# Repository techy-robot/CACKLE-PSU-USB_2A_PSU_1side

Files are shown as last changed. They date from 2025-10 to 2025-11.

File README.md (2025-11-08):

---
modified: 2025-11-07T22:09:18-07:00
---

# USB Only PSU one side

> [!TIP]
> This board is part of a larger modular control board ecosystem, [CACKLE](https://github.com/techy-robot/CACKLE)

The main ICs are an mcu, and a 5v 2a switching regulator. The system can theoretically handle 20 volt spikes, but this is mostly meant for 5v output on one side only.

The MCU has several purposes:
- Manage USB-C PD negotiations over the CC pins (built in PHY)
- Report voltage & current sensor data over the bus
- Act as a host adapter to convert USB or SPI data to rs485 bus commands and back. Helpful for debugging the system via a laptop, or if your main compute board needs to control the motors and sensors and doesn't have RS485 built in.

The CH32X035G8U6 MCU will be used, though I may swap to a STM32G071 x8/xB for sourcing reasons, which also implements usb pd (no usb comm) but is a little more expensive. To get a  QFN28/32 chip with USB PD, I need the N version. My options on digikey are STM32G071GBU6N ($2.74) and STM32G071KBU6N ($2.94)

Also looking for USB C connectors on [DigiKey](https://www.digikey.com/en/products/filter/usb-dvi-hdmi-connector-assemblies/312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).

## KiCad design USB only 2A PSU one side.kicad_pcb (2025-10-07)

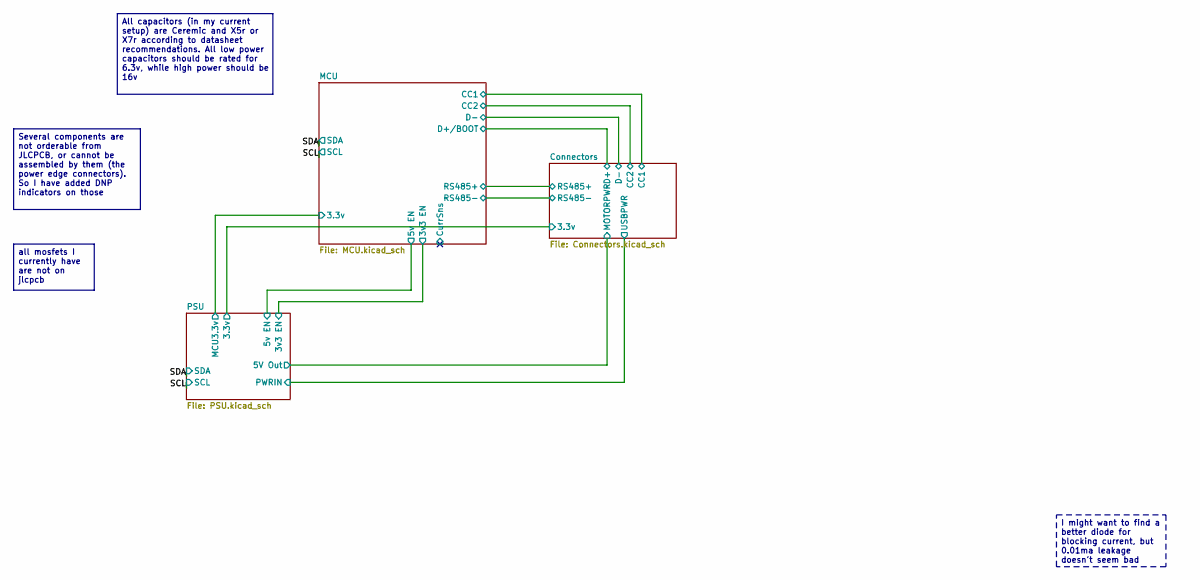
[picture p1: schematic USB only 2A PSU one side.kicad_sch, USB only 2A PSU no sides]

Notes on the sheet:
All capacitors (in my current setup) are Ceremic and X5r or X7r according to datasheet recommendations. All low power capacitors should be rated for 6.3v, while high power should be 16v
Several components are not orderable from JLCPCB, or cannot be assembled by them (the power edge connectors). So I have added DNP indicators on those
all mosfets I currently have are not on jlcpcb
I might want to find a better diode for blocking current, but 0.01ma leakage doesn't seem bad

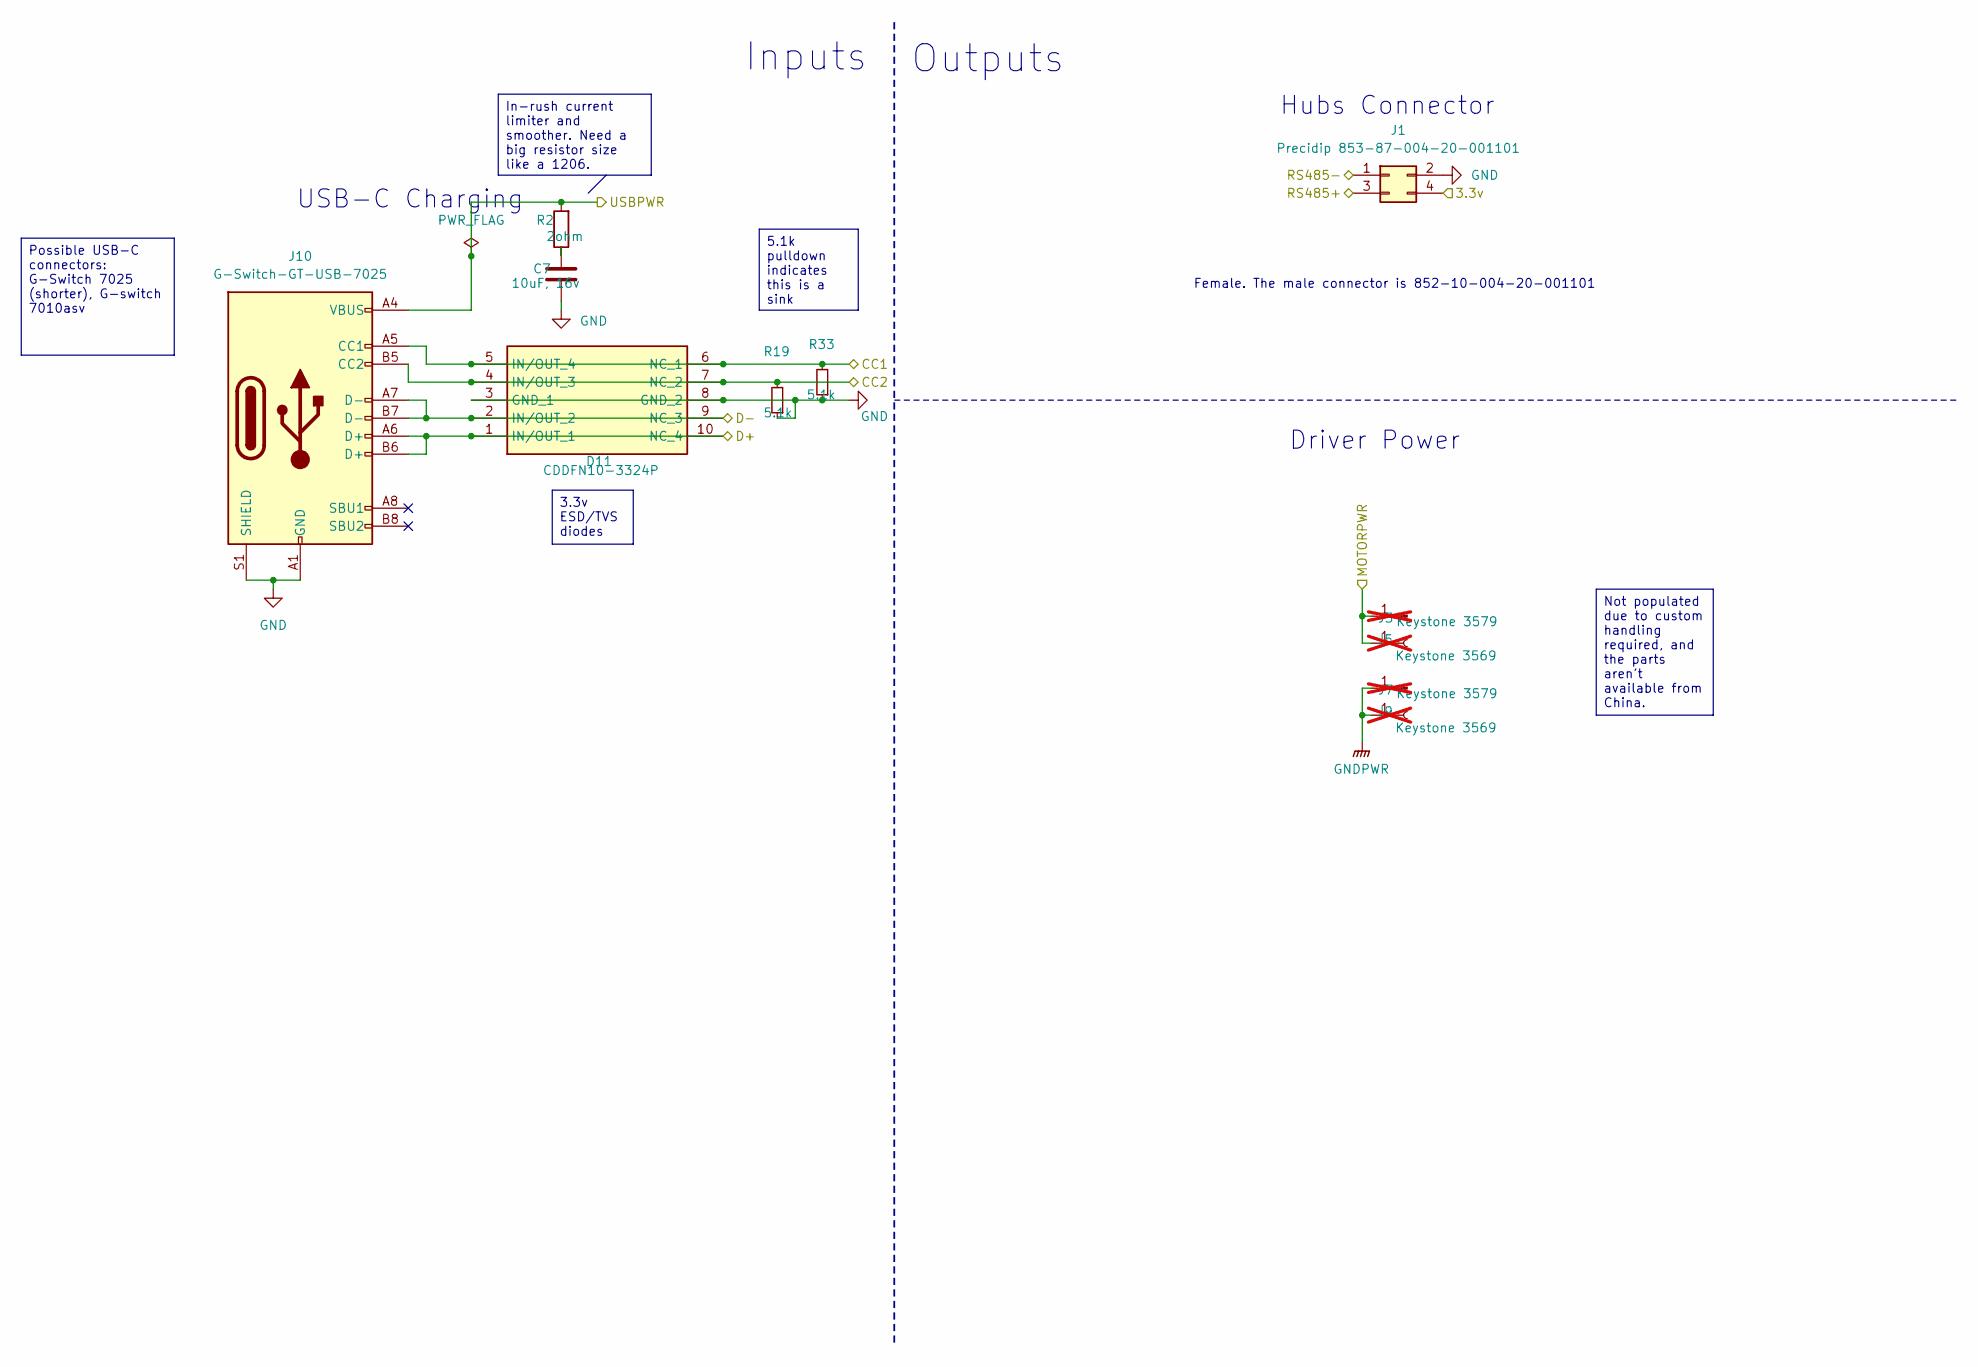
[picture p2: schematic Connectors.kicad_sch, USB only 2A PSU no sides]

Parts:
C7: 10uF, 16v; C_0805_2012Metric; LCSC C15850
D11: CDDFN10-3324P; CDDFN103324P; Mouser Part Number 652-CDDFN10-3324P
J1: Precidip 853-87-004-20-001101; PinHeader_2x02_P1.27mm_Horizontal
J3, J7: Keystone 3579; Keystone_3579; not fitted
J5, J9: Keystone 3569; Keystone_3569_half; not fitted
J10: G-Switch-GT-USB-7025; USB_C_G-Switch_GT-USB-7025-JLCPCBv; LCSC C963213
R2: 2ohm; R_0805_2012Metric; LCSC C17521
R19, R33: 5.1k; R_0805_2012Metric; LCSC C25905

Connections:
/Connectors/3.3v: J1.4; also elsewhere on the board
/Connectors/CC1: D11.5 (IN/OUT_4), D11.6 (NC_1), J10.A5 (CC1), R33.2; also elsewhere on the board
/Connectors/CC2: D11.4 (IN/OUT_3), D11.7 (NC_2), J10.B5 (CC2), R19.2; also elsewhere on the board
/Connectors/D+: D11.1 (IN/OUT_1), D11.10 (NC_4), J10.A6 (D+), J10.B6 (D+); also elsewhere on the board
/Connectors/D-: D11.2 (IN/OUT_2), D11.9 (NC_3), J10.A7 (D-), J10.B7 (D-); also elsewhere on the board
/Connectors/RS485+: J1.3; also elsewhere on the board
/Connectors/RS485-: J1.1; also elsewhere on the board
/Connectors/USBPWR: J10.A4 (VBUS), J10.A9 (VBUS), J10.B4 (VBUS), J10.B9 (VBUS), R2.2; also elsewhere on the board
/PSU/5V Out: J3.1, J5.1; also elsewhere on the board
GND: C7.2, D11.3 (GND_1), D11.8 (GND_2), J1.2, J10.A1 (GND), J10.A12 (GND), J10.B1 (GND), J10.B12 (GND), J10.S1 (SHIELD), R19.1, R33.1; also elsewhere on the board
GNDPWR: J7.1, J9.1; also elsewhere on the board
unnamed: C7.1, R2.1

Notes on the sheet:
Female. The male connector is 852-10-004-20-001101
Outputs
USB-C Charging
Inputs
Driver Power
Hubs Connector
In-rush current limiter and smoother. Need a big resistor size like a 1206.
5.1k pulldown indicates this is a sink
Possible USB-C connectors: G-Switch 7025 (shorter), G-switch 7010asv
3.3v ESD/TVS diodes
Not populated due to custom handling required, and the parts aren't available from China.

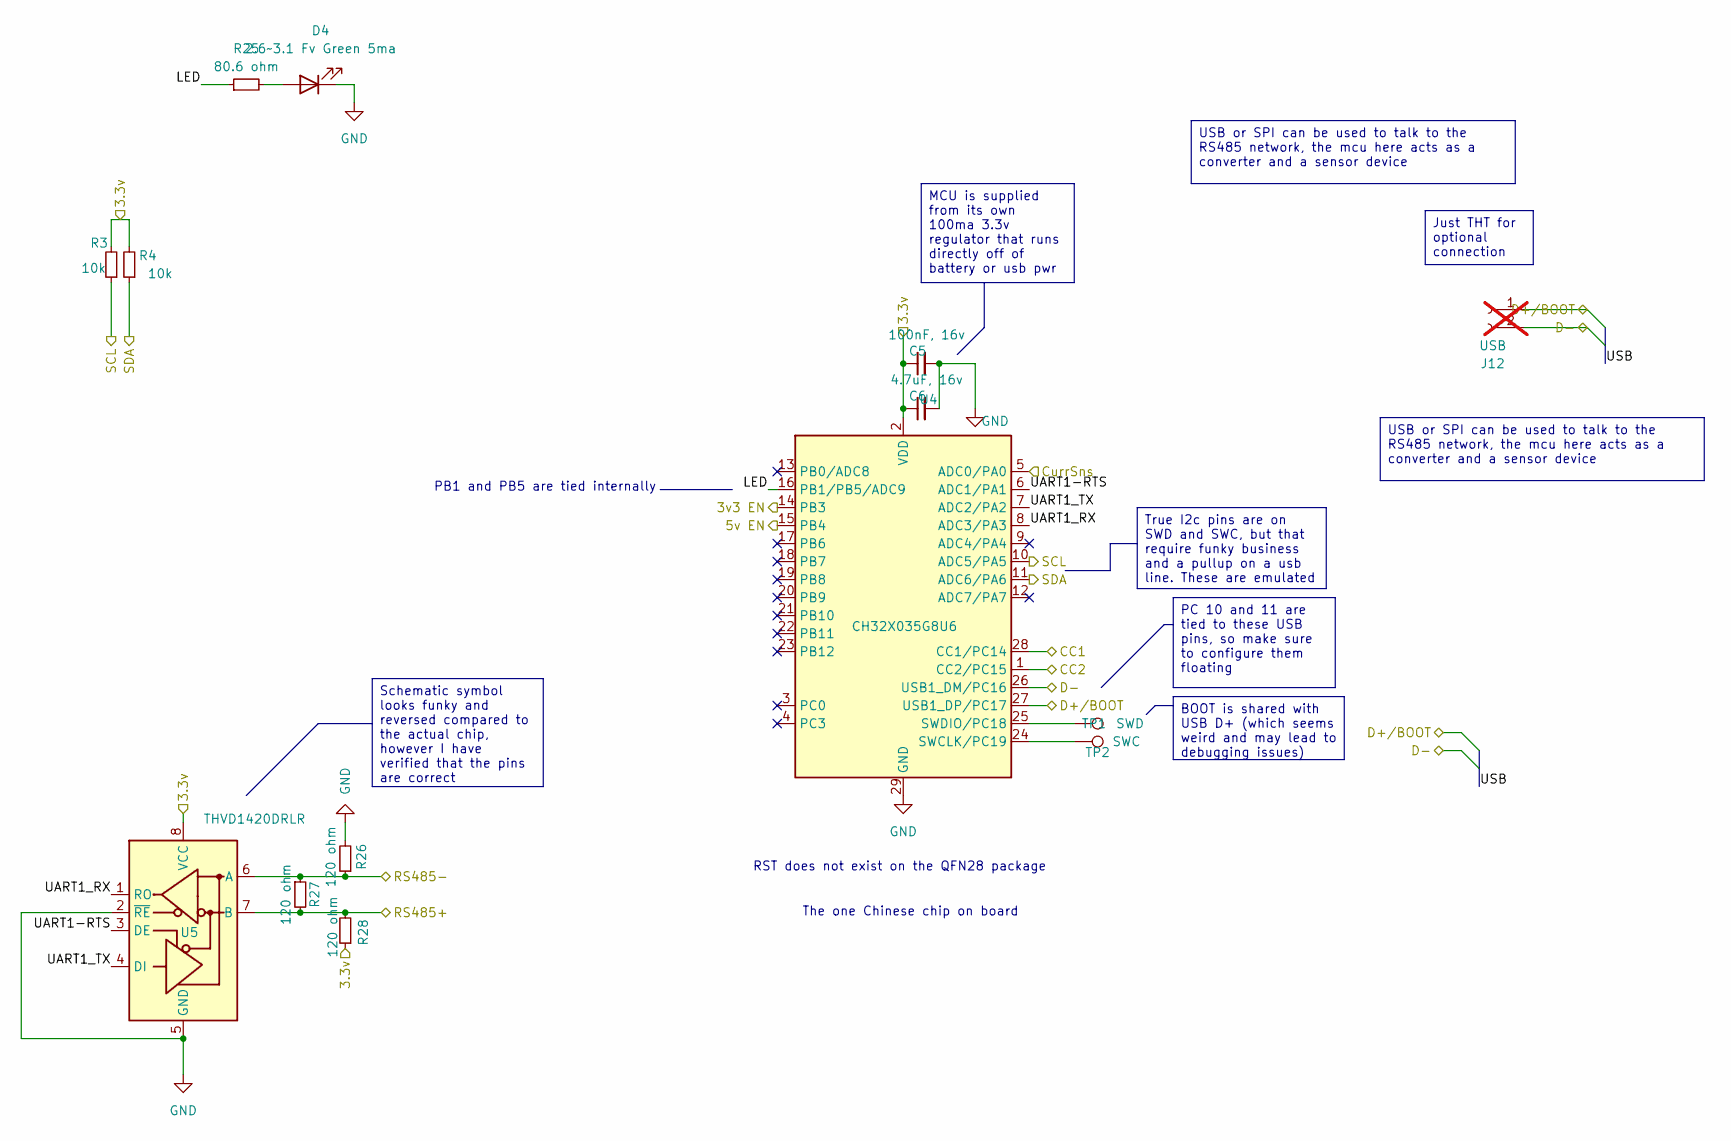
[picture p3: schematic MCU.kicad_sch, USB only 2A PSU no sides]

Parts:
C5: 100nF, 16v; C_0805_2012Metric; LCSC C1525
C6: 4.7uF, 16v; C_0805_2012Metric; LCSC C19666
D4: 2.6~3.1 Fv Green 5ma; LED_0603_1608Metric_Pad1.05x0.95mm_HandSolder; LCSC C3028858
J12: USB; PinHeader_1x02_P1.27mm_Vertical; not fitted
R3, R4: 10k; R_0805_2012Metric; LCSC C25744
R25: 80.6 ohm; R_0805_2012Metric; LCSC C185392
R26, R27, R28: 120 ohm; R_0805_2012Metric; LCSC C25079
TP1: SWD; TestPoint_Pad_D1.0mm
TP2: SWC; TestPoint_Pad_D1.0mm
U4: CH32X035G8U6; QFN-28-1EP_4x4mm_P0.4mm_EP2.8x2.8mm; LCSC C7437027
U5: THVD1420DRLR; SOT-583-8

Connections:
/Connectors/CC1: U4.28 (CC1/PC14); also elsewhere on the board
/Connectors/CC2: U4.1 (CC2/PC15); also elsewhere on the board
/Connectors/D+: J12.1, U4.27 (USB1_DP/PC17); also elsewhere on the board
/Connectors/D-: J12.2, U4.26 (USB1_DM/PC16); also elsewhere on the board
/Connectors/RS485+: R27.2, R28.2, U5.7 (B); also elsewhere on the board
/Connectors/RS485-: R26.1, R27.1, U5.6 (A); also elsewhere on the board
/MCU/3.3v: C5.1, C6.1, R3.2, R4.2, R28.1, U4.2 (VDD), U5.8 (VCC); also elsewhere on the board
/MCU/3v3 EN: U4.14 (PB3); also elsewhere on the board
/MCU/5v EN: U4.15 (PB4); also elsewhere on the board
/MCU/CurrSns: U4.5 (ADC0/PA0)
/MCU/LED: R25.1, U4.16 (PB1/PB5/ADC9)
/MCU/UART1-RTS: U4.6 (ADC1/PA1), U5.3 (DE)
/MCU/UART1_RX: U4.8 (ADC3/PA3), U5.1 (RO)
/MCU/UART1_TX: U4.7 (ADC2/PA2), U5.4 (DI)
/SCL: R3.1, U4.10 (ADC5/PA5); also elsewhere on the board
/SDA: R4.1, U4.11 (ADC6/PA6); also elsewhere on the board
GND: C5.2, C6.2, D4.1 (K), R26.2, U4.29 (GND), U5.2 (~RE), U5.5 (GND); also elsewhere on the board
unnamed: D4.2 (A), R25.2
unnamed: TP2.1, U4.24 (SWCLK/PC19)
unnamed: TP1.1, U4.25 (SWDIO/PC18)

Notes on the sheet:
PB1 and PB5 are tied internally
RST does not exist on the QFN28 package
The one Chinese chip on board
USB or SPI can be used to talk to the RS485 network, the mcu here acts as a converter and a sensor device
MCU is supplied from its own 100ma 3.3v regulator that runs directly off of battery or usb pwr
Just THT for optional connection
PC 10 and 11 are tied to these USB pins, so make sure to configure them floating
Schematic symbol looks funky and reversed compared to the actual chip, however I have verified that the pins are correct
True I2c pins are on SWD and SWC, but that require funky business and a pullup on a usb line. These are emulated
BOOT is shared with USB D+ (which seems weird and may lead to debugging issues)

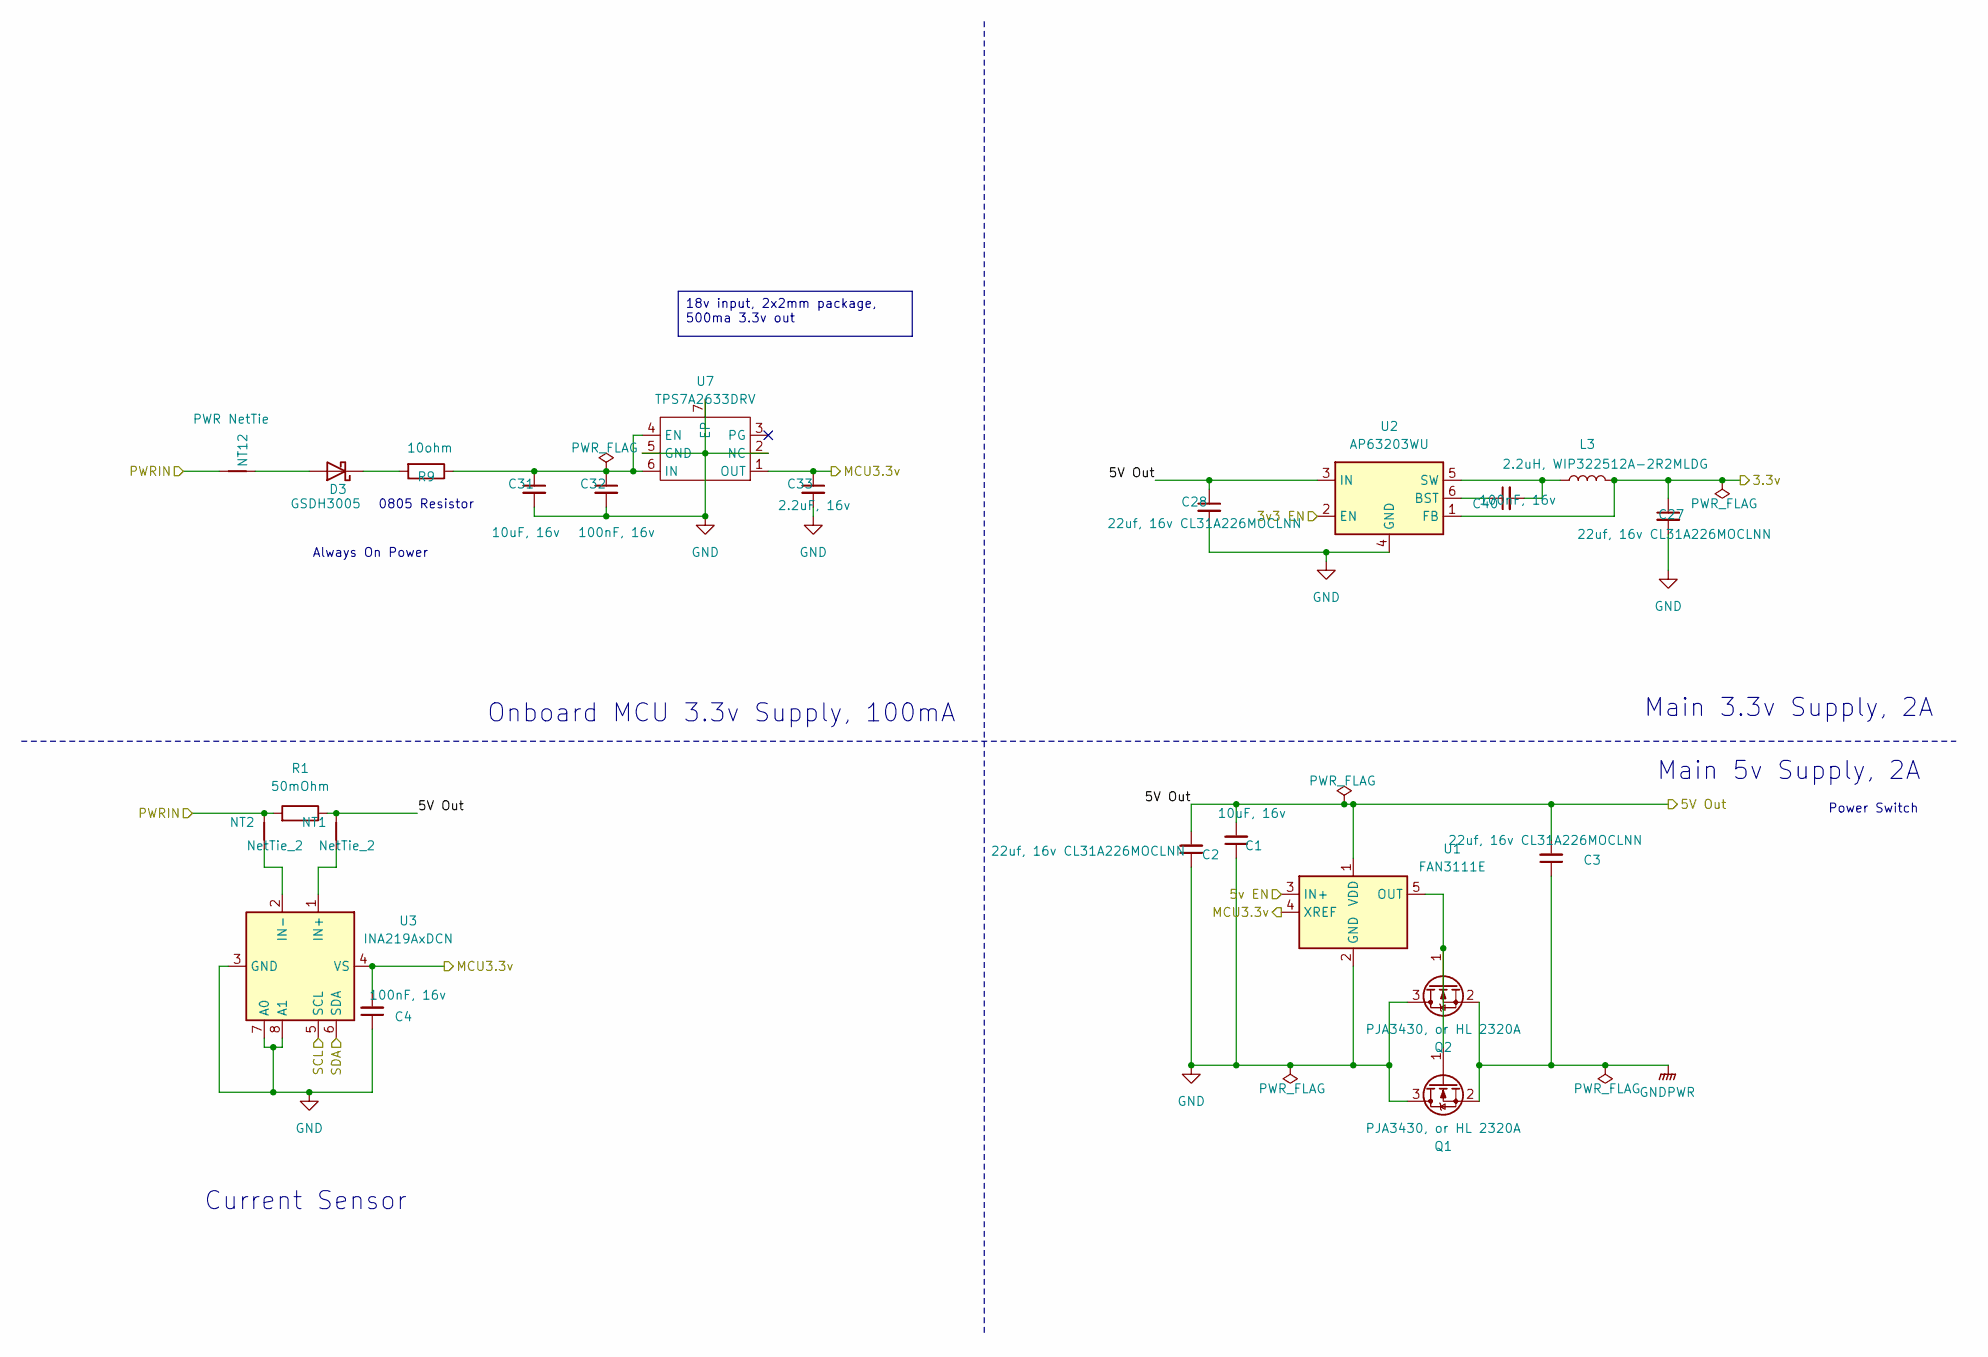
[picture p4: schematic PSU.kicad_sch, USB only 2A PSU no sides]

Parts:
C1, C31: 10uF, 16v; C_0805_2012Metric; LCSC C96446
C2, C3, C27, C28: 22uf, 16v CL31A226MOCLNN; C_1206_3216Metric; LCSC C159758
C4, C40: 100nF, 16v; C_0805_2012Metric; LCSC C14663
C32: 100nF, 16v; C_0805_2012Metric; LCSC C1525
C33: 2.2uF, 16v; C_0805_2012Metric; LCSC C12530
D3: GSDH3005; D_0402_1005Metric; LCSC C2837790
L3: 2.2uH, WIP322512A-2R2MLDG; L_1008_2520Metric; LCSC C5832372
NT1, NT2: NetTie_2; NetTie-2_SMD_Pad0.2mm
NT12: PWR NetTie; NetTie-2_SMD_Pad0.28mm
Q1, Q2: PJA3430, or HL 2320A; SC-59
R1: 50mOhm; R_2512_6332Metric
R9: 10ohm; R_0805_2012Metric; LCSC C17415
U1: FAN3111E; SOT-23-5
U2: AP63203WU; TSOT-23-6; LCSC C780769
U3: INA219AxDCN; SOT-23-8
U7: TPS7A2633DRV; WSON-6-1EP_2x2mm_P0.65mm_EP1x1.6mm; LCSC C2876256

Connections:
/Connectors/3.3v: C27.1, L3.2, U2.1 (FB); also elsewhere on the board
/Connectors/USBPWR: NT2.2, NT12.2, R1.2; also elsewhere on the board
/MCU/3.3v: C4.2, C33.1, U1.4 (XREF), U3.4 (VS), U7.1 (OUT); also elsewhere on the board
/MCU/3v3 EN: U2.2 (EN); also elsewhere on the board
/MCU/5v EN: U1.3 (IN+); also elsewhere on the board
/PSU/5V Out: C1.2, C2.2, C3.2, C28.1, NT1.2, R1.1, U1.1 (VDD), U2.3 (IN); also elsewhere on the board
/SCL: U3.5 (SCL); also elsewhere on the board
/SDA: U3.6 (SDA); also elsewhere on the board
GND: C1.1, C2.1, C4.1, C27.2, C28.2, C31.2, C32.2, C33.2, Q1.3 (D), Q2.3 (D), U1.2 (GND), U2.4 (GND), U3.3 (GND), U3.7 (A0), U3.8 (A1), U7.2 (NC), U7.5 (GND), U7.7 (EP); also elsewhere on the board
GNDPWR: C3.1, Q1.2 (S), Q2.2 (S); also elsewhere on the board
unnamed: D3.2 (A), NT12.1
unnamed: D3.1 (K), R9.2
unnamed: Q1.1 (G), Q2.1 (G), U1.5 (OUT)
unnamed: C40.1, U2.6 (BST)
unnamed: C40.2, L3.1, U2.5 (SW)
unnamed: NT1.1, U3.1 (IN+)
unnamed: NT2.1, U3.2 (IN-)
unnamed: C31.1, C32.1, R9.1, U7.4 (EN), U7.6 (IN)

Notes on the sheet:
Current Sensor
Power Switch
Always On Power
Onboard MCU 3.3v Supply, 100mA
Main 3.3v Supply, 2A
0805 Resistor
Main 5v Supply, 2A
18v input, 2x2mm package, 500ma 3.3v out

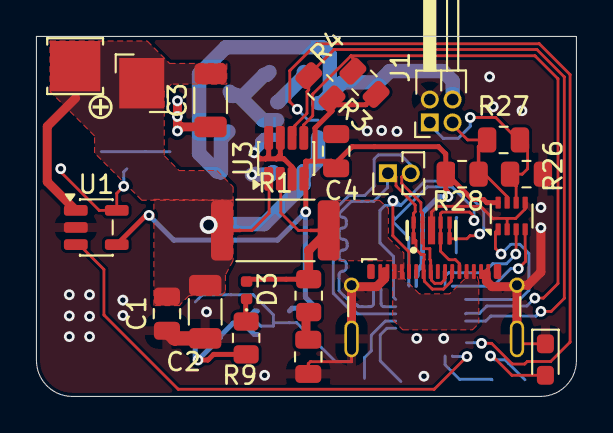
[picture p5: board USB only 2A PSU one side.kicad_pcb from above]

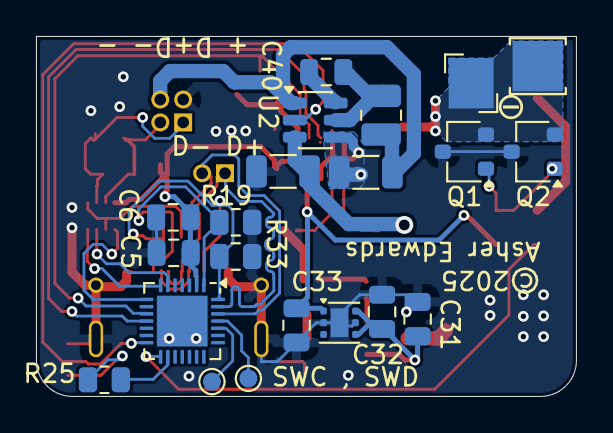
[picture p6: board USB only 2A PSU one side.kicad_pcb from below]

Board: 2 copper layers, 30.0 x 20.0 mm, 48 parts (21 on the bottom side), 32 nets.

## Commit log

2025-10-07 Renamed PSU to suite design
    [Connectors.kicad_sch, MCU.kicad_sch, PSU.kicad_sch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]
2025-10-10 Moved all current production files to Proto 1.
    I haven't made a 2nd prototype yet
    [bom.csv, designators.csv, positions.csv]
2025-10-10 Added alt mating connector
    [Connectors.kicad_sch]
2026-07-14 chore: remove production files from tracking
    Migrating these files to github releases
    [bom.csv, designators.csv, positions.csv]

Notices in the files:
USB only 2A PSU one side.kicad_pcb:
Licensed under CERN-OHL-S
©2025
